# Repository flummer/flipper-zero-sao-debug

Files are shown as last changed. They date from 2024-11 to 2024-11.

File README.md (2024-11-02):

# Badgelife SAO Debug Tool for Flipper Zero

This is a relatively simple expansion board for the Flipper Zero, that has the proper connectors to attach SAOs and communicate with the SAO via I2C and the GPIO pins.

It can also be used to communicate with a badge, essentially making the Flipper Zero into an SAO, electrically, which could be usefull for debugging or developing communication between badge as SAOs.

## Designed in KiCad v8.99 (nightly)

To open the project, you will need to install a recent nightly build (og v9 or newer when released), KiCad v8 or earlier won't open this design directly.

## License

The hardware design of the `main` branch of this repository is released under the following license:

* the "Creative Commons Attribution-ShareAlike 4.0 International License"
  (CC BY-SA 4.0) full text of this license is included in the LICENSE file
  and a copy can also be found at
  [http://creativecommons.org/licenses/by-sa/4.0/](http://creativecommons.org/licenses/by-sa/4.0/)

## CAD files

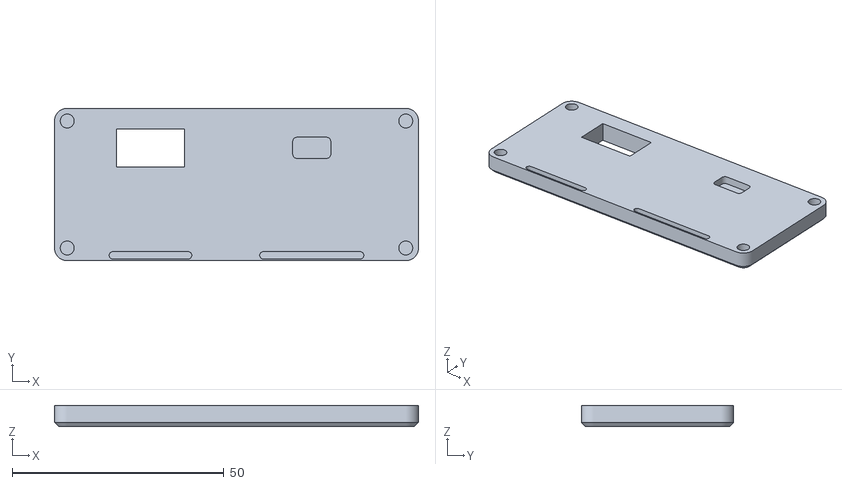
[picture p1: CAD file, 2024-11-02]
case/cover.stl
86.0 x 36.0 x 5.00

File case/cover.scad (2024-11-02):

/* 
 * Handle for SAO Cable Extension
 *
 * Design: hxr.social/@thomasflummer
 *
 * License: CC-BY-SA
 *
 */

module cover(length, width, height, corner_radius)
{
    difference()
    {
        union()
        {
            hull()
            {
                for(x = [-1, 1])
                {
                    for(y = [-1, 1])
                    {
                        translate([x*(length/2 - corner_radius), y*(width/2 - corner_radius), height/2-1])
                            cylinder(r = corner_radius-1, h = height, center = true, $fn = 150);
                    }
                }

                for(x = [-1, 1])
                {
                    for(y = [-1, 1])
                    {
                        translate([x*(length/2 - corner_radius), y*(width/2 - corner_radius), height/2])
                            cylinder(r = corner_radius, h = height, center = true, $fn = 150);
                    }
                }
            }        
        }
        union()
        {
            // insert cutouts
            for(x = [-1, 1])
            {
                for(y = [-1, 1])
                {
                    translate([x*(length/2 - corner_radius), y*(width/2 - corner_radius), (height)/2])
                        cylinder(d = 3.3, h =  height+0.01, center = true, $fn = 50);
                }
            }

            // back sao connector
            translate([-length/2+22.68, width/2-9.33, 0])
                cube([16, 9, 10], center = true);
                
            // front sao connector pins
            translate([length/2-25.22, width/2-9.33, 0])
            hull()
            {
                for(x = [-1, 1])
                {
                    for(y = [-1, 1])
                    {
                        translate([x*(9/2 - 1), y*(5/2 - 1), height - 2/2])
                            cylinder(r = 1, h = 2.1, center = true, $fn = 50);
                    }
                }
            }

            // flipper zero pins
            translate([-20.32, -(width/2-1.27), 0])
            hull()
            {
                for(x = [-1, 1])
                {
                    for(y = [-1, 1])
                    {
                        translate([x*(17.78/2), y*(0), height - 2/2])
                            cylinder(r = 1.27-0.4, h = 2.1, center = true, $fn = 50);
                    }
                }
            }

            translate([17.78, -(width/2-1.27), 0])
            hull()
            {
                for(x = [-1, 1])
                {
                    for(y = [-1, 1])
                    {
                        translate([x*(22.86/2), y*(0), height - 2/2])
                            cylinder(r = 1.27-0.4, h = 2.1, center = true, $fn = 50);
                    }
                }
            }
            
        }
    }
}

cover(86, 36, 4, 3);

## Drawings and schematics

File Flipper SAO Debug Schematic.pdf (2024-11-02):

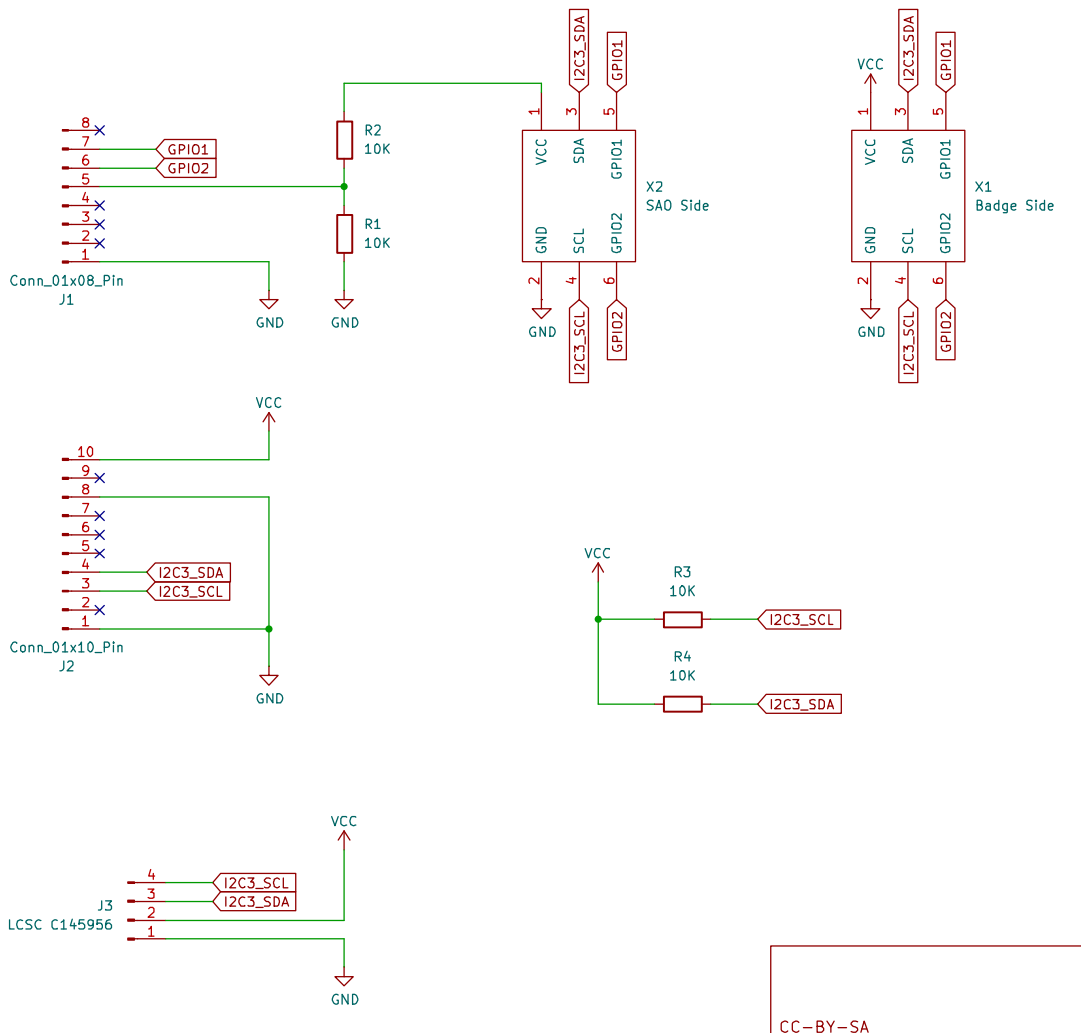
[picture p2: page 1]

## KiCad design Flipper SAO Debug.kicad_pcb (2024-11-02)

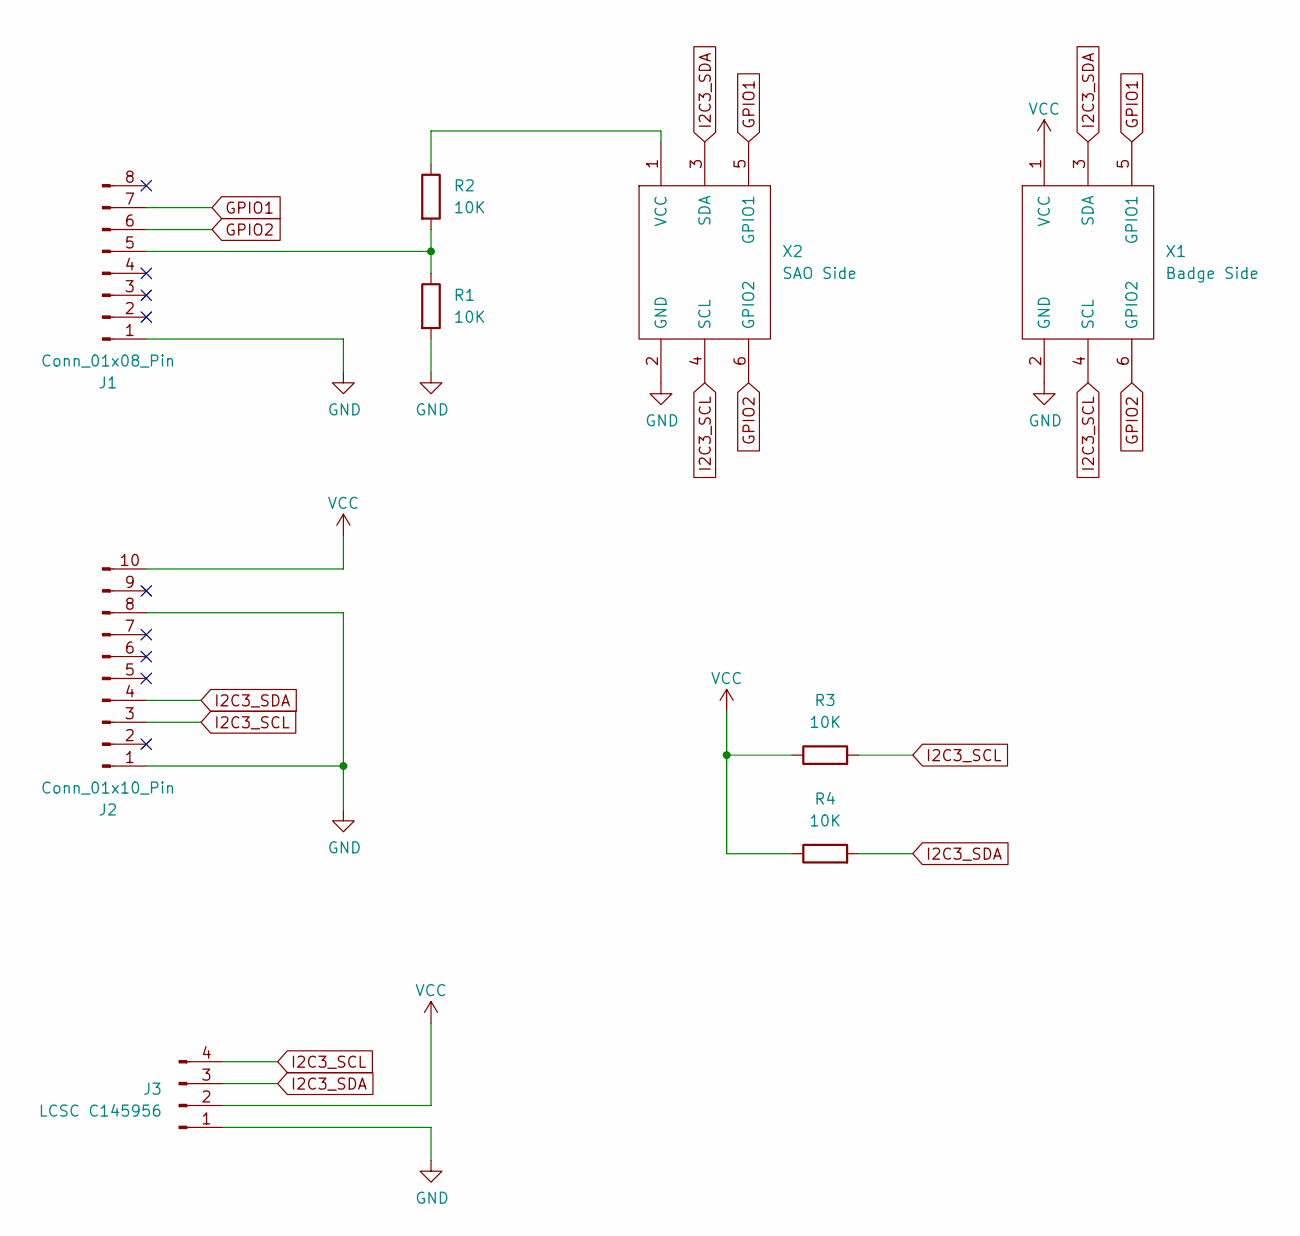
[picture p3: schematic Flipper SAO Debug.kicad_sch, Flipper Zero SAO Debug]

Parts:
J1: Conn_01x08_Pin; PinHeader_1x08_P2.54mm_Horizontal
J2: Conn_01x10_Pin; PinHeader_1x10_P2.54mm_Horizontal
J3: LCSC C145956; JST_SH_SM04B-SRSS-TB_1x04-1MP_P1.00mm_Horizontal
R1, R2, R3, R4: 10K; R_0603_1608Metric
X1: Badge Side; Badgelife-SAOv169-BADGE-2x3
X2: SAO Side; Badgelife-SAOv169-SAO-2x3

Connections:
GND: J1.1, J2.1, J2.8, J3.1, R1.2, X1.2 (GND), X2.2 (GND)
GPIO1: J1.7, X1.5 (GPIO1), X2.5 (GPIO1)
GPIO2: J1.6, X1.6 (GPIO2), X2.6 (GPIO2)
I2C3_SCL: J2.3, J3.4, R3.2, X1.4 (SCL), X2.4 (SCL)
I2C3_SDA: J2.4, J3.3, R4.2, X1.3 (SDA), X2.3 (SDA)
unnamed: J1.5, R1.1, R2.2
unnamed: R2.1, X2.1 (VCC)
VCC: J2.10, J3.2, R3.1, R4.1, X1.1 (VCC)

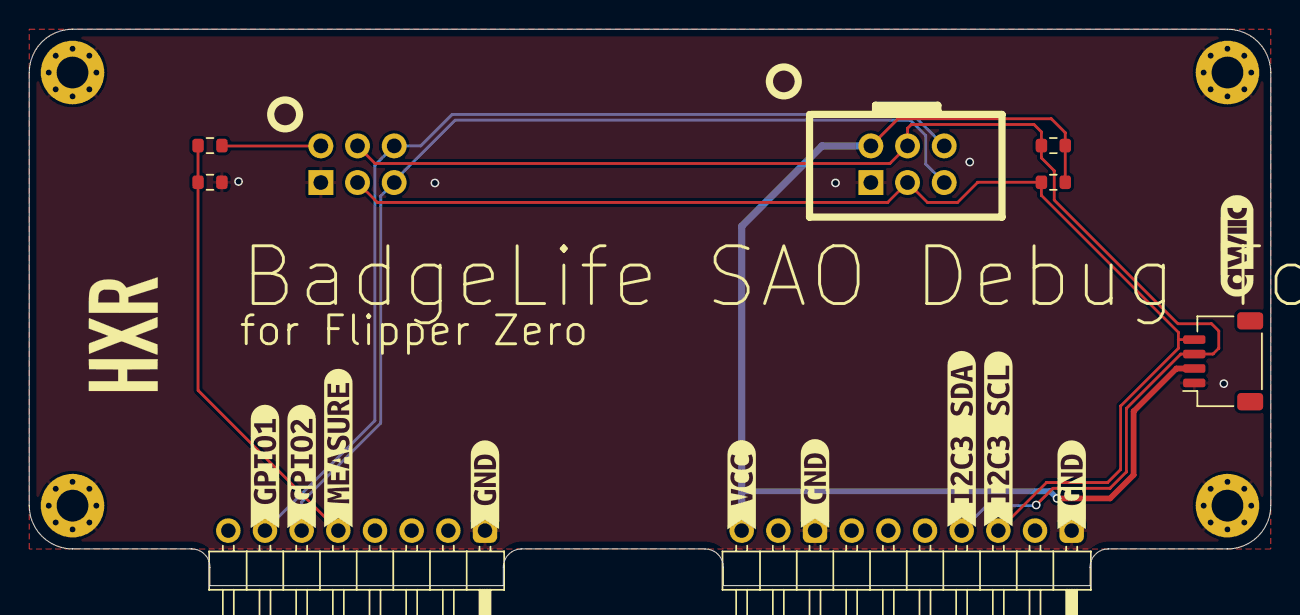
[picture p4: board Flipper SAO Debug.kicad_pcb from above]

Board: 2 copper layers, 86.0 x 38.5 mm, 18 parts (0 on the bottom side), 8 nets.

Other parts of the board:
kibuzzard-67014A6A: G***; kibuzzard-67014A6A
kibuzzard-670147AD: G***; kibuzzard-670147AD
kibuzzard-670147DA: G***; kibuzzard-670147DA
kibuzzard-670147E8: G***; kibuzzard-670147E8
kibuzzard-670147FB: G***; kibuzzard-670147FB
kibuzzard-6701479F: G***; kibuzzard-6701479F
kibuzzard-67014762, kibuzzard-67014762#2, kibuzzard-67014762#3: G***; kibuzzard-67014762
